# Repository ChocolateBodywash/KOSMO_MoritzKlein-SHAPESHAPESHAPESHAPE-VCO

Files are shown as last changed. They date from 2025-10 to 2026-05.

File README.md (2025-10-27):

## KOSMO Format - SHAPE SHAPE SHAPE SHAPE VCO

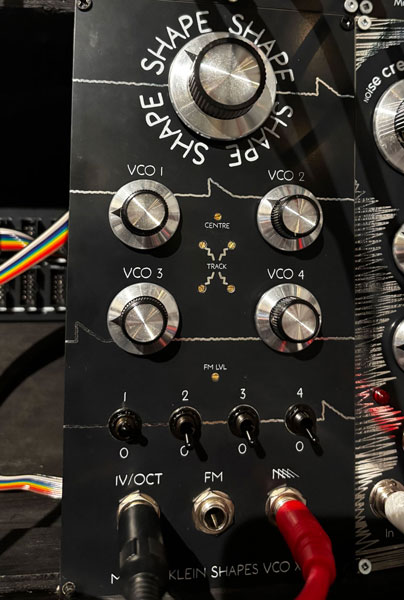
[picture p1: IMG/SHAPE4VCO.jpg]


A KOSMO format of Moritz Klein’s "Shapes VCO" with a few added features

Moritz Klein’s VCA (https://www.youtube.com/watch?v=QBatvo8bCa4)

The shapes VCO was probably one of the first synth projects I ever did, so this one is dear to my heart.
I love this VCO! Parts are easy to find, it stays in tune and it sounds awesome.

I felt I needed to push it further, the 40106 schmitt trigger inverter contains 6 inverters. What if I used all of them?
Well that was too much, but with the amount of op amps I needed I worked out 4 was the most I could get. I'm pretty sure it would be impossible to fit anymore without making this a massive 20cm module or something..

### Features

- For ease of use, there is one CV input that goes to a buffered multiple circuit. All four then get mixed into one output.

- Realizing it would be impossible to tune, I added a switch for each VCO. This also makes it easy to add or remove VCOs on the fly.

- Instead of a coarse tuning knob, I added an octave switch. This required a precision shunt voltage reference and a series of voltage dividers. The only catch was that it needed to be a negative voltage, so I inverted the whole thing. Problem solved.

- One easy win was adding a Look Mum No Computer link cable, this makes it compatible with the 1221 ocsilator expander. 

- The FM knob wouldn’t fit, so I used a trimpot instead. A compromise had to be made somewhere.

- There is also a center trimpot that acts like a coarse tuning knob just in case. All of these controls get summed together.

---
Note: This was created by a hobbyist with no formal engineering training outside various late night YouTube binges. 
I’ve confirmed these designs to work but I make no guarantees on the design working efficiently.. or working at all.

Additional credit: Analog Output (Richard Holmes) for footprint libraries and front panel templates.

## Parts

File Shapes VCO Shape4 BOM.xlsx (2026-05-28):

Shape Shape Shape Shape VCO
Reference | Value | Package | Qty
C1,C4,C6,C8 | 1uF | Box Style Film Capacitor | 4
C2,C11,C12,C13,C14,C15,C16,C17, C18,C19,C21,C22 | 0.1uF | Ceramic Disc Capacitor | 12
C3,C5,C7,C9 | 2.2nF | Box Style Film Capacitor | 4
C10,C20 | 47uF | Electrolytic Capacitor | 2
D1,D2,D3,D4 | 1N4148 | Diode_THT | 4
D5,D6 | 1N5819 | Diode_THT | 2
E1 | Link Cable | EurorackPower_Shrouded | 1
E2 | Conn_02x05_Pin | EurorackPower_Shrouded | 1
J1 | Conn_01x07_Pin | Molex_1x07_P2.54mm_Vertical | 1
J2 | CV | Jack_6.35mm | 1
J3,J5 | 01x06_Pin | PinHeader_1x06_P2.54mm_Vertical | 2
J4 | FM | Jack_6.35mm | 1
J6 | Saw Out | Jack_6.35mm | 1
Q1,Q3,Q5,Q7 | BC558 | THT:TO-92_Inline | 4
Q2,Q4,Q6,Q8 | BC548 | THT:TO-92_Inline | 4
R1,R2,R3,R4,R5,R7,R10,R11,R13,R15, R16,R17,R18,R19,R25,R27,R33,R34, R36,R37,R38,R39,R40,R41,R47,R48, R49, R50,R56 | 100K | Metal Film 1/4 Resistor | 29
R6,R26,R42,R51 | 47K | Metal Film 1/4 Resistor | 4
R8,R28,R35,R43,R52 | 1M | Metal Film 1/4 Resistor | 5
R9 | 6.8K | Metal Film 1/4 Resistor | 1
R12,R30,R44,R54 | 560K | Metal Film 1/4 Resistor | 4
R14,R31,R46,R55 | 4.7K | Metal Film 1/4 Resistor | 4
R20,R21,R22,R23,R24 | 10K M | Metal Film 1/4 Resistor | 5
R29,R32 | 10K | Metal Film 1/4 Resistor | 2
R45 | 1K | Metal Film 1/4 Resistor | 1
R53,R57 | 10 | Metal Film 1/4 Resistor | 2
RV1 | 100K | Potentiometer_Vertical preset pot | 1
RV2 | 1M | Potentiometer_Vertical preset pot | 1
RV3,RV4,RV5,RV6 | 1K | Potentiometer_Vertical preset pot | 4
SW1,SW2,SW3,SW4 | SW_SPDT | SPDT switch | 4
TH1,TH2,TH3,TH4,TH5,TH6,TH7,TH8 | Therm 10K | NTC Thermistor | 8
U1,U3,U5,U6 | TL074 | DIP-14_W7.62mm | 4
U2 | LM4040CIZ-5 | TO-92_precision voltage regulator | 1
U4 | 40106 | DIP-14_W7.62mm_LongPads | 1
VR1,VR2,VR3,VR4 | B100K Fine | Potentiometer_Single_Vertical | 4

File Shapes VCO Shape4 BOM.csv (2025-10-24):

Reference | Value | Datasheet | Package | Qty
C1,C4,C6,C8 | 1uF | ~ | Box Style Film Capacitor | 4
C2,C11,C12,C13,C14,C15,C16,C17,C18,C19,C21,C22 | 0.1uF | ~ | Ceramic Disc Capacitor | 12
C3,C5,C7,C9 | 2.2nF | ~ | Box Style Film Capacitor | 4
C10,C20 | 47uF | ~ | Electrolytic Capacitor | 2
D1,D2,D3,D4 | 1N4148 | https://assets.nexperia.com/documents/data-sheet/1N4148_1N4448.pdf | Diode_THT:D_DO-35_SOD27_P7.62mm_Horizontal | 4
D5,D6 | 1N5819 | http://www.vishay.com/docs/88525/1n5817.pdf | Diode_THT:D_DO-41_SOD81_P10.16mm_Horizontal | 2
E1 | Link Cable | ~ | Pins_2x05_2.54mm_TH_EurorackPower_Shrouded | 1
E2 | Conn_02x05_Pin | ~ | Pins_2x05_2.54mm_TH_EurorackPower_Shrouded | 1
J1 | Conn_01x07_Pin | ~ | Connector_Molex:Molex_KK-254_AE-6410-07A_1x07_P2.54mm_Vertical | 1
J2 | CV | ~ | Jack_6.35mm | 1
J3,J5 | 01x06_Pin | ~ | Connector_PinHeader_2.54mm:PinHeader_1x06_P2.54mm_Vertical | 2
J4 | FM | ~ | Jack_6.35mm | 1
J6 | Saw Out | ~ | Jack_6.35mm | 1
Q1,Q3,Q5,Q7 | BC558 | https://www.onsemi.com/pub/Collateral/BC556BTA-D.pdf | Package_TO_SOT_THT:TO-92_Inline | 4
Q2,Q4,Q6,Q8 | BC548 | https://www.onsemi.com/pub/Collateral/BC550-D.pdf | Package_TO_SOT_THT:TO-92_Inline | 4
R1,R2,R3,R4,R5,R7,R10,R11,R13,R15,R16,R17,R18,R19,R25,R27,R33,R34,R36,R37,R38,R39,R40,R41,R47,R48,R49,R50,R56 | 100K | ~ | Metal Film 1/4 Resistor | 29
R6,R26,R42,R51 | 47K | ~ | Metal Film 1/4 Resistor | 4
R8,R28,R35,R43,R52 | 1M | ~ | Metal Film 1/4 Resistor | 5
R9 | 6.8K | ~ | Metal Film 1/4 Resistor | 1
R12,R30,R44,R54 | 560K | ~ | Metal Film 1/4 Resistor | 4
R14,R31,R46,R55 | 4.7K | ~ | Metal Film 1/4 Resistor | 4
R20,R21,R22,R23,R24 | 10K M | ~ | Metal Film 1/4 Resistor | 5
R29,R32 | 10K | ~ | Metal Film 1/4 Resistor | 2
R45 | 1K | ~ | Metal Film 1/4 Resistor | 1
R53,R57 | 10 | ~ | Metal Film 1/4 Resistor | 2
RV1 | 100K | ~ | Potentiometer_Vertical preset pot | 1
RV2 | 1M | ~ | Potentiometer_Vertical preset pot | 1
RV3,RV4,RV5,RV6 | 1K | ~ | Potentiometer_Vertical preset pot | 4
SW1,SW2,SW3,SW4 | SW_SPDT | ~ | SPDT switch | 4
TH1,TH2,TH3,TH4,TH5,TH6,TH7,TH8 | Therm 10K | ~ | NTC Thermistor | 8
U1,U3,U5,U6 | TL074 | http://www.ti.com/lit/ds/symlink/tl071.pdf | DIP-14_W7.62mm | 4
U2 | LM4040CIZ-5 | http://www.ti.com/lit/ds/symlink/lm4040-n.pdf | TO-92_Inline_Wide precision voltage regulator | 1
U4 | 40106 | https://assets.nexperia.com/documents/data-sheet/HEF40106B.pdf | Package_DIP:DIP-14_W7.62mm_LongPads | 1
VR1,VR2,VR3,VR4 | B100K Fine | ~ | Potentiometer_Alpha_RD901F-40-00D_Single_Vertical | 4

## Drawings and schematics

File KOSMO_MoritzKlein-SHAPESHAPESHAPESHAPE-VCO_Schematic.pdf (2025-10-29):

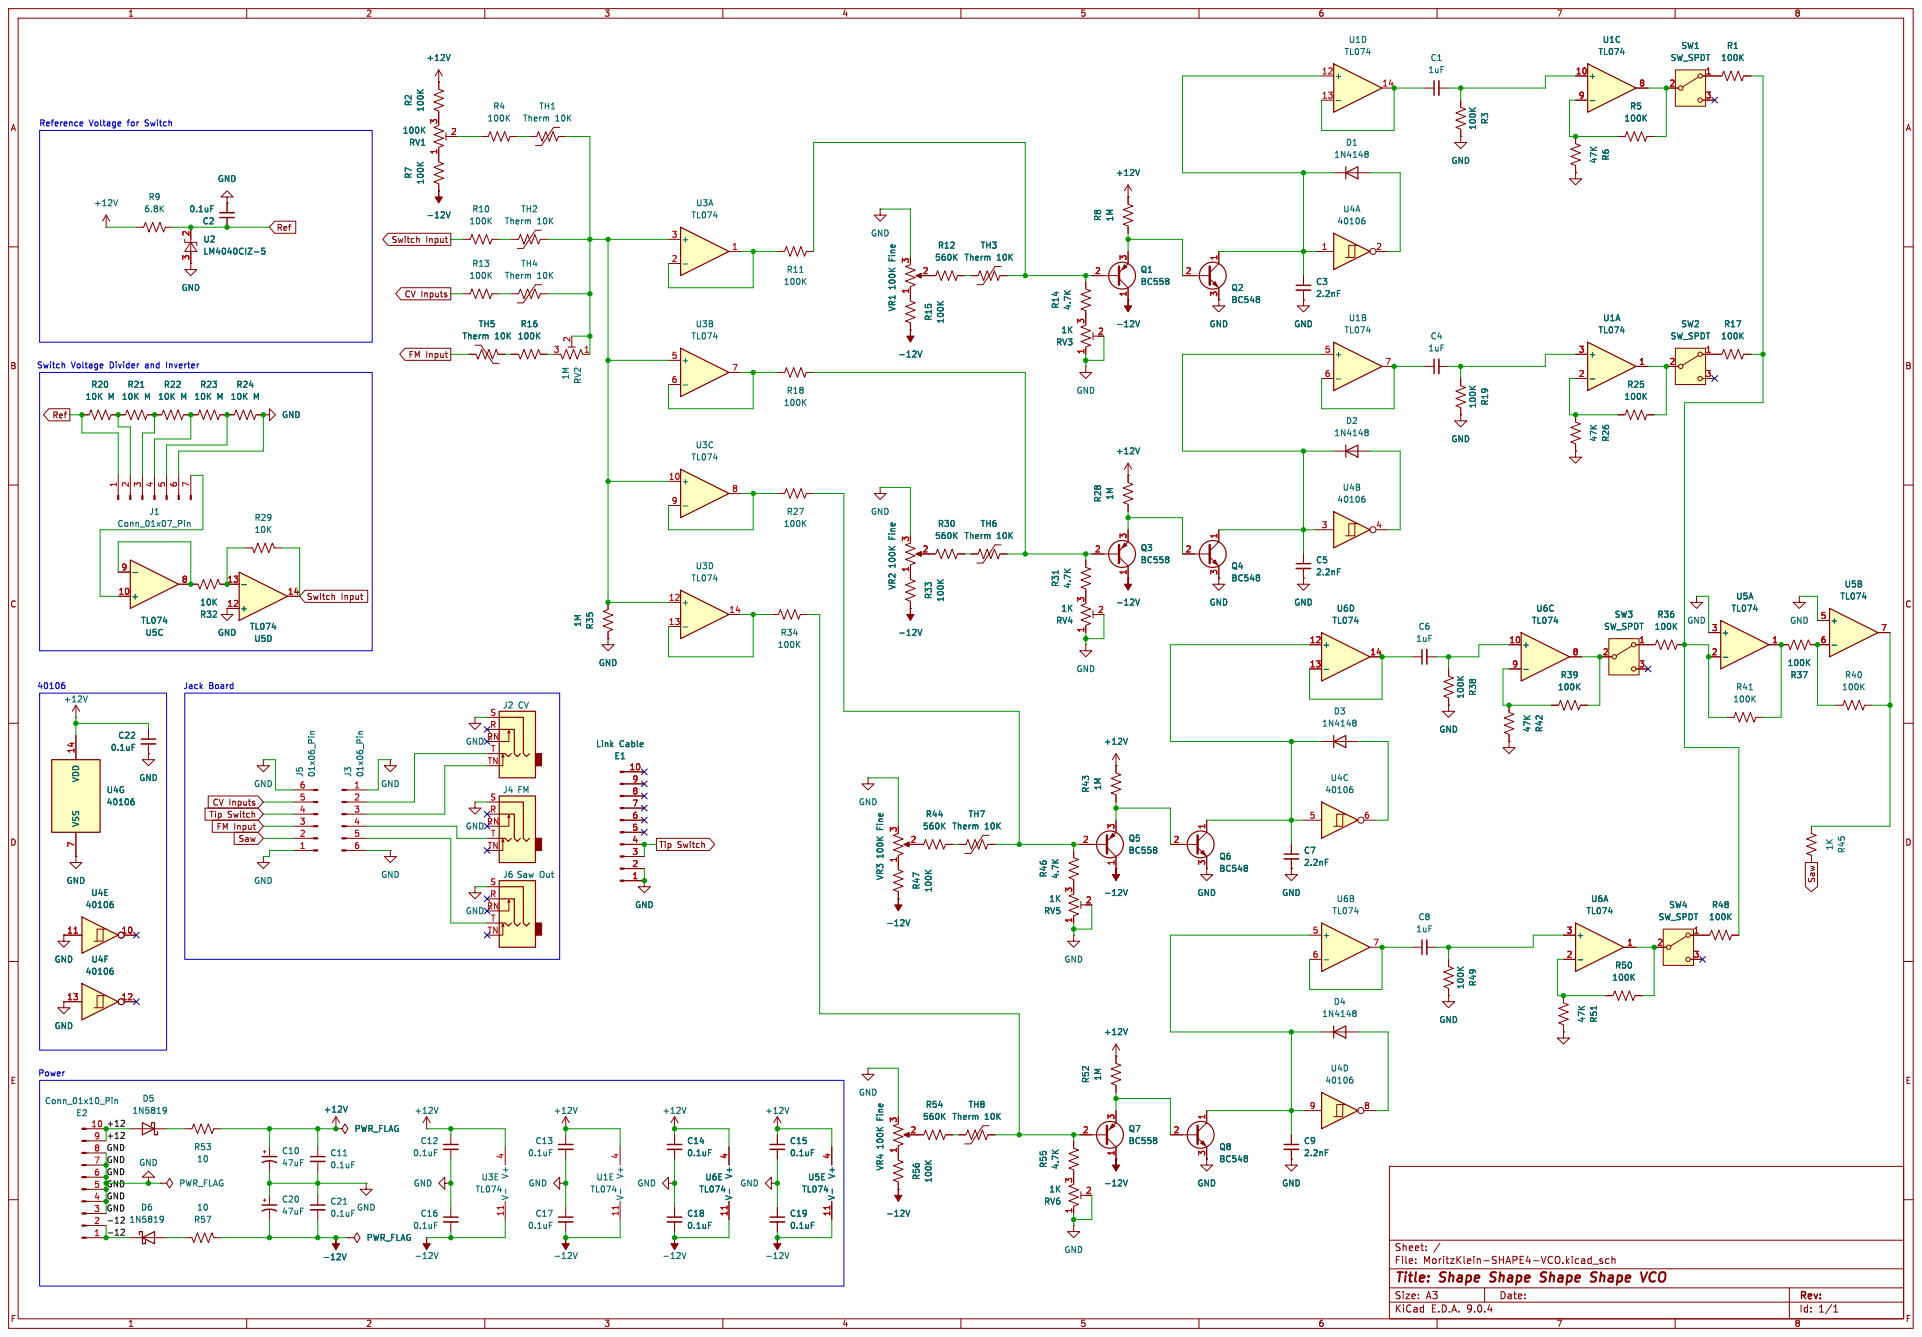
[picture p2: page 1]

Reference Voltage for Switch

File: MoritzKlein-SHAPE4-VCO.kicad_sch Sheet: /

Id: 1/1 Title: Shape Shape Shape Shape VCO

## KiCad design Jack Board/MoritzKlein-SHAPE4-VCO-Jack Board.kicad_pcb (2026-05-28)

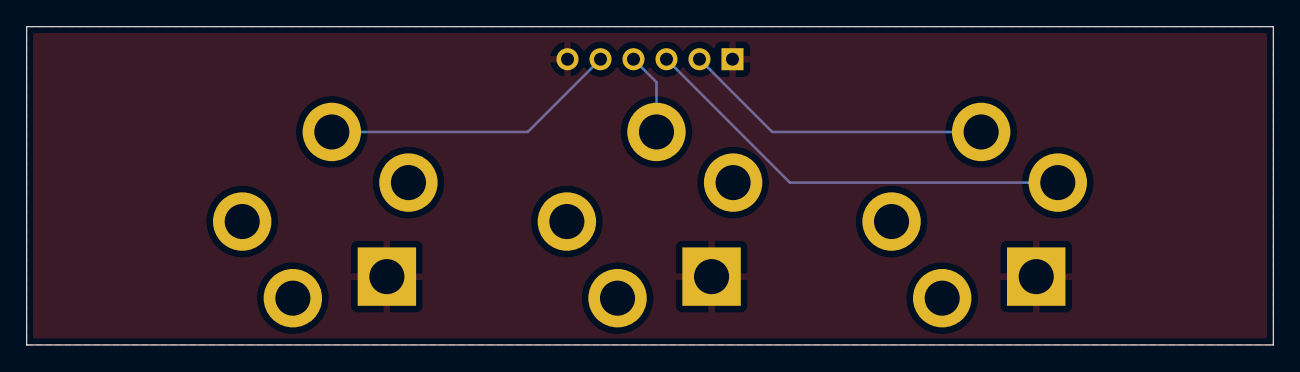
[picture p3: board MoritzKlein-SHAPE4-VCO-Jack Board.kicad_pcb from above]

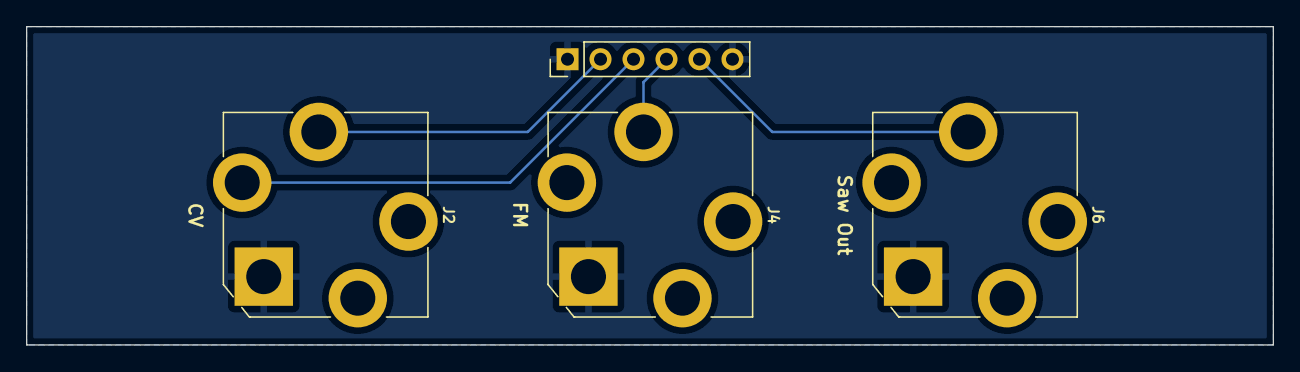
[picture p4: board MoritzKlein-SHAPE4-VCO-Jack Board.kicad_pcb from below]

Board: 2 copper layers, 96.0 x 24.5 mm, 4 parts (4 on the bottom side), 5 nets.

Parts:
J2: CV; Jack_6.35mm_PJ_629HAN
J3: 01x06_Pin; PinHeader_1x06_P2.54mm_Vertical_Centered
J4: FM; Jack_6.35mm_PJ_629HAN
J6: Saw Out; Jack_6.35mm_PJ_629HAN

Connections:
GND: J2.S, J3.1, J3.6, J4.S, J6.S
unnamed: J2.T, J3.2
unnamed: J2.TN, J3.3
unnamed: J3.4, J4.T
unnamed: J3.5, J6.T

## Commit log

2025-10-05 Update MoritzKlein-SHAPE4-VCO-Jack Board.kicad_pro
2025-10-24 Create Shapes VCO Shape4 BOM.csv
    [Shapes VCO Shape4 BOM.csv]
2026-05-28 Gerbers Added
    [MoritzKlein-SHAPE4-VCO-FrontPanel.kicad_pcb, MoritzKlein-SHAPE4-VCO-Jack Board.kicad_pcb, MoritzKlein-SHAPE4-VCO.kicad_pcb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]
